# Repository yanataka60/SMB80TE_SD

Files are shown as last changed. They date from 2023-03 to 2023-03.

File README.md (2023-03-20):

# SHARP SM-B-80TEにSD-Cardとのロード、セーブ機能

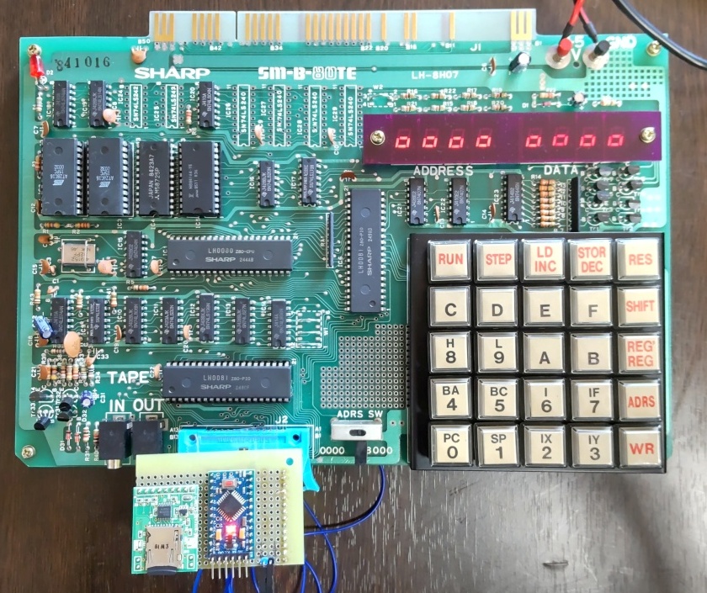
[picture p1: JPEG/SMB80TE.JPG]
TITLE


　シリアル同期通信によりSM-B-80TEとSD_ACCESS(ARDUINO+SD-CARD)とのロード、セーブを提供するルーチンです。

## 必要なもの
　Z80PIO 1個(標準搭載のZ80PIOとは別のZ80PIOが必要)

　SD_ACCESS基板(「SD_ACCESS」リポジトリ参照)

　2716 1個(MONITOR ROMを差し替えるなら2716 2個)

　ピンヘッダ、フラットケーブル、ブレッドボード・ジャンパーワイヤ等(SD_ACCESS基板の接続方法により適宜用意してください)

## 接続方法
SD_ACCESS(ARDUINO+SD-CARD)と拡張Z80PIOを接続します。拡張Z80PIO外部端子から接続する例を示します。

SD_ACCESS(ARDUINO+SD-CARD)については、「SD_ACCESS」リポジトリを参照してください。

|Arduino(SD_ACCESS)|拡張Z80PIO外部端子(SM-B-80TE)|
| --- | --- |
|5V|B8　5V|
|GND|B7　GND|
|9(FLG:output)|A4　PORTC BIT1(CHK:input)|
|8(OUT:output)|B4　PORTC BIT0(IN:input)|
|7(CHK:input)|A3　PORTC BIT3(FLG:output)|
|6(IN:input)|B3　PORTC BIT2(OUT:output)|

　今回はTK-85用に用意したSD_ACCESS(ARDUINO+SD-CARD)を流用して繋いでいます。

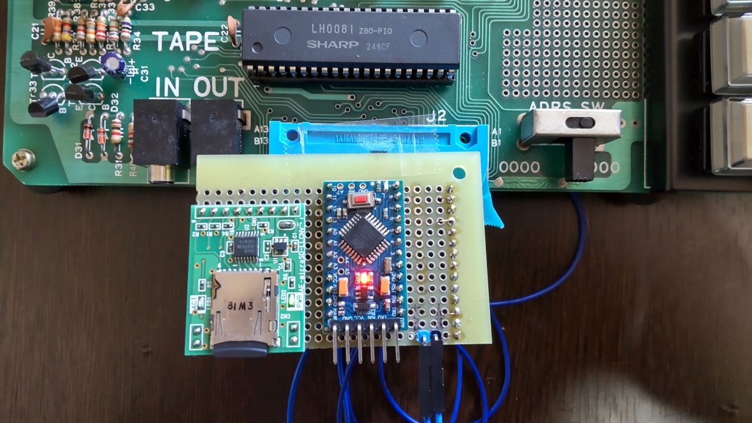
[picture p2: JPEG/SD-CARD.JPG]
SD-Cardアダプタ


### SM-B-80TE専用のSD_ACCESS基板を作ってみました。

　基板データは、Kicadフォルダにあります。

#### 部品
|番号|品名|数量|備考|
| --- | --- | --- | --- |
|J1|細ピンヘッダ又は基板用リードフレーム|1|秋月電子通商 PHA-1x40SG又はSHP-001|
||J2、J3のいずれか|||
|J2|Micro_SD_Card_Kit|1|秋月電子通商 AE-microSD-LLCNV|
|J3|MicroSD Card Adapter|1|Arduino等に使われる5V電源に対応したもの|
|U2|Arduino_Pro_Mini_5V|1||
||40PinICソケット|1||
|U1|Z80PIO|1|SM-B-80TEに増設済みであれば引き抜いて使用|

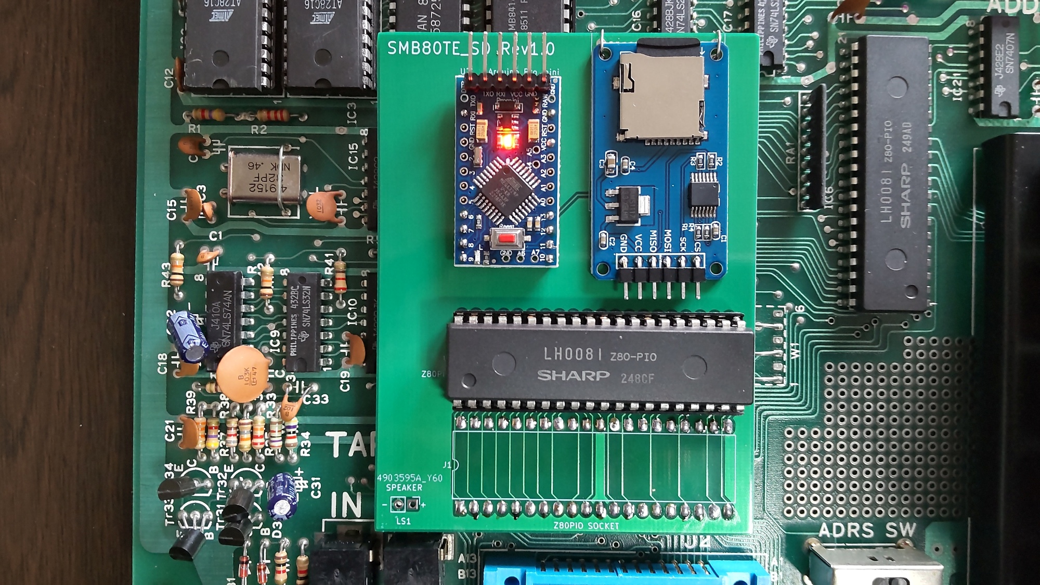
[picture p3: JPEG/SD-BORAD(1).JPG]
SD-BOARD1


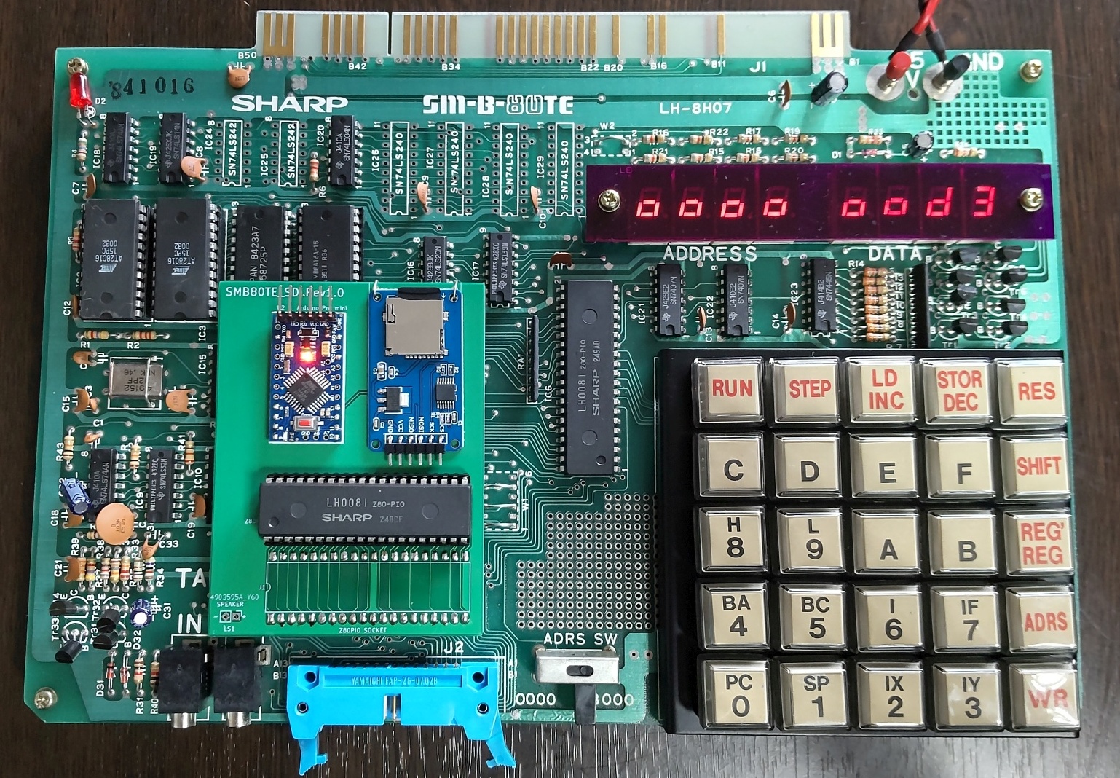
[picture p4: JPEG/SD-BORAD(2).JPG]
SD-BOARD2


## ROMへの書込み
　file_trans_SMB80TE.binを2716に書き込み、SM-B-80TEのIC3 ROMソケットに挿し込みます。

## MONITOR-ROMの差し替え
　SD用LOADルーチン(8800H)、SAVEルーチン(8803H)を直接実行することでSDへのLOAD、SAVEが行えますが、MONITOR-ROMにパッチを当て、SHIFT+A(SD-LOAD)、SHIFT+B(SD-SAVE)で使えるようにすると便利です。

　MONITOR-ROMの内容を読み出し、バイナリエディタ等で以下を修正し、2716に書き込み、MONITOR-ROMと差し替えます。

|ADDRESS(実ADDRESS)|変更前|変更後|
| --- | --- | --- |
|0060(8060)|FE|C3|
|0061(8061)|0C|06|
|0062(8062)|CA|88|

## SD-CARD
　FAT16又はFAT32が認識できます。

## 扱えるファイル
　拡張子btkとなっているバイナリファイルです。

　ファイル名は0000～FFFFまでの16進数4桁を付けてください。(例:1000.btk)

　この16進数4桁がSM-B-80TEからSD-Card内のファイルを識別するファイルNoとなります。

　btkの構造は、バイナリファイル本体データの先頭に開始アドレス、終了アドレスの4Byteのを付加した形になっています。(SAMPLEフォルダの0001.bin、0001.btkを参照)

　パソコンのクロスアセンブラ等でSM-B-80TE用の実行binファイルを作成したらバイナリエディタ等で先頭に開始アドレス、終了アドレスの4Byteを付加し、ファイル名を変更したものをSD-Cardのルートディレクトリに保存すればSM-B-80TEから呼び出せるようになります。

## 操作方法
　異常が無いと思われるのにエラーとなってしまう場合にはSD-CardアダプタのArduinoとSM-B-80TEの両方をリセットしてからやり直してみてください。

### Load
 (直接実行する場合)8800H

 (MONITOR-ROMを差し替えた場合)SHIFT+A

　ADDRESS LEDに「L-F」と表示されるのでファイルNo(xxxx)を16進数4桁で入力してWRキーを押します。

　　　xxxx.BTKをBTKヘッダ情報で示されたアドレスにロードします。ただし、07B0H～07FFHまでの範囲はライトプロテクトされます。

　正常にLoadが完了するとアドレス部にスタートアドレス、データ部にエンドアドレスが表示されます。スタートアドレスが実行開始アドレスであればそのままRUNキーを押すことでプログラムが実行できます。

　「F0F0F0F0F0」と表示された場合はSD-Card未挿入、「F1F1F1F1F1」と表示された場合はファイルNoのファイルが存在しない場合です。確認してください。

### Save
 (直接実行する場合)8803H

 (MONITOR-ROMを差し替えた場合)SHIFT+B

　ADDRESS LEDに「S-F」と表示されるのでファイルNo(xxxx)を16進数4桁で入力してWRキーを押します。

　ADDRESS LEDに「S-S」と表示されるのでSAVEしたい範囲のSTART ADDRESSを16進数4桁で入力してWRキーを押します。

　ADDRESS LEDに「S-E」と表示されるのでSAVEしたい範囲のEND ADDRESSを16進数4桁で入力してWRキーを押します。

　正常にSaveが完了するとアドレス部にスタートアドレス、データ部にエンドアドレスが表示されます。

　「FFFFFFFF」と表示された場合はSD-Card未挿入です。確認してください。

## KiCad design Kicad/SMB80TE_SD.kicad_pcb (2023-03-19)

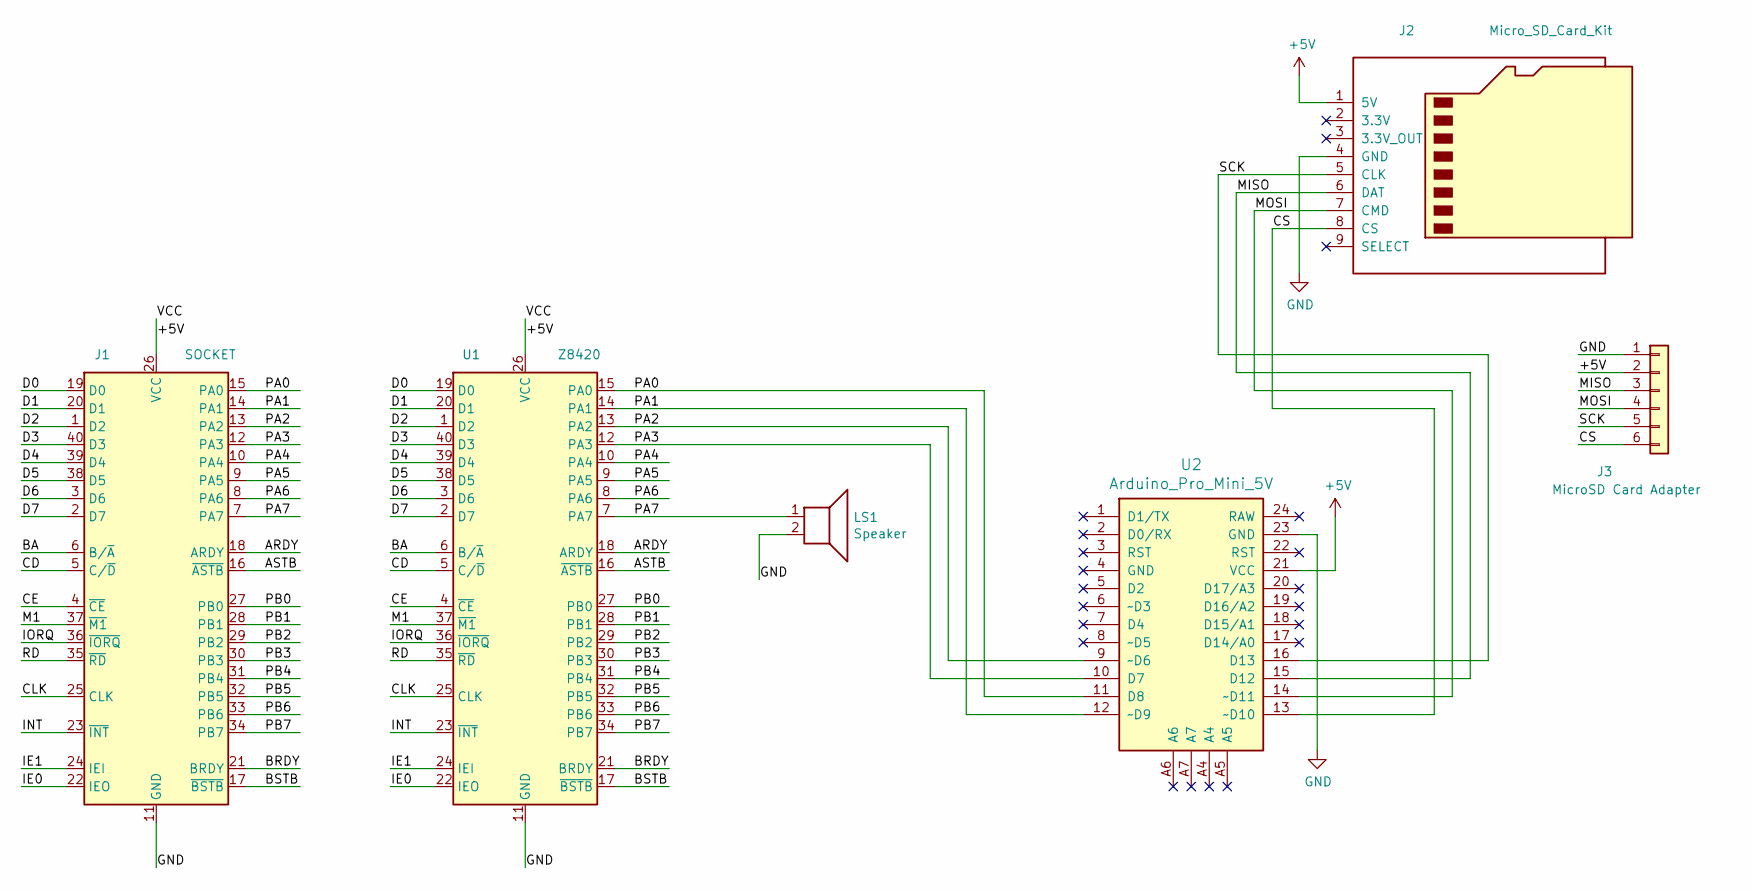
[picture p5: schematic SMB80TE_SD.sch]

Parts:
J1: SOCKET; DIP-40_W15.24mm_LongPads
J2: Micro_SD_Card_Kit; AE-microSD-LLCNV
J3: MicroSD Card Adapter; PinSocket_1x06_P2.54mm_Vertical
LS1: Speaker; PinHeader_1x02_P2.54mm_Vertical
U1: Z8420; DIP-40_W15.24mm_LongPads
U2: Arduino_Pro_Mini_5V; Arduino_Pro_Mini

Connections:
+5V: J1.26 (VCC), J2.1 (5V), J3.2, U1.26 (VCC), U2.21 (VCC)
/ARDY: J1.18 (ARDY), U1.18 (ARDY)
/ASTB: J1.16 (~ASTB~), U1.16 (~ASTB~)
/BA: J1.6 (B/~A~), U1.6 (B/~A~)
/BRDY: J1.21 (BRDY), U1.21 (BRDY)
/BSTB: J1.17 (~BSTB~), U1.17 (~BSTB~)
/CD: J1.5 (C/~D~), U1.5 (C/~D~)
/CE: J1.4 (~CE~), U1.4 (~CE~)
/CLK: J1.25 (CLK), U1.25 (CLK)
/CS: J2.8 (CS), J3.6, U2.13 (~~D10)
/D0: J1.19 (D0), U1.19 (D0)
/D1: J1.20 (D1), U1.20 (D1)
/D2: J1.1 (D2), U1.1 (D2)
/D3: J1.40 (D3), U1.40 (D3)
/D4: J1.39 (D4), U1.39 (D4)
/D5: J1.38 (D5), U1.38 (D5)
/D6: J1.3 (D6), U1.3 (D6)
/D7: J1.2 (D7), U1.2 (D7)
/IE0: J1.22 (IEO), U1.22 (IEO)
/IE1: J1.24 (IEI), U1.24 (IEI)
/INT: J1.23 (~INT~), U1.23 (~INT~)
/IORQ: J1.36 (~IORQ~), U1.36 (~IORQ~)
/M1: J1.37 (~M1~), U1.37 (~M1~)
/MISO: J2.6 (DAT), J3.3, U2.15 (D12)
/MOSI: J2.7 (CMD), J3.4, U2.14 (~~D11)
/PA0: J1.15 (PA0), U1.15 (PA0), U2.11 (D8)
/PA1: J1.14 (PA1), U1.14 (PA1), U2.12 (~~D9)
/PA2: J1.13 (PA2), U1.13 (PA2), U2.9 (~~D6)
/PA3: J1.12 (PA3), U1.12 (PA3), U2.10 (D7)
/PA4: J1.10 (PA4), U1.10 (PA4)
/PA5: J1.9 (PA5), U1.9 (PA5)
/PA6: J1.8 (PA6), U1.8 (PA6)
/PA7: J1.7 (PA7), LS1.1, U1.7 (PA7)
/PB0: J1.27 (PB0), U1.27 (PB0)
/PB1: J1.28 (PB1), U1.28 (PB1)
/PB2: J1.29 (PB2), U1.29 (PB2)
/PB3: J1.30 (PB3), U1.30 (PB3)
/PB4: J1.31 (PB4), U1.31 (PB4)
/PB5: J1.32 (PB5), U1.32 (PB5)
/PB6: J1.33 (PB6), U1.33 (PB6)
/PB7: J1.34 (PB7), U1.34 (PB7)
/RD: J1.35 (~RD~), U1.35 (~RD~)
/SCK: J2.5 (CLK), J3.5, U2.16 (D13)
GND: J1.11 (GND), J2.4 (GND), J3.1, LS1.2, U1.11 (GND), U2.23 (GND)

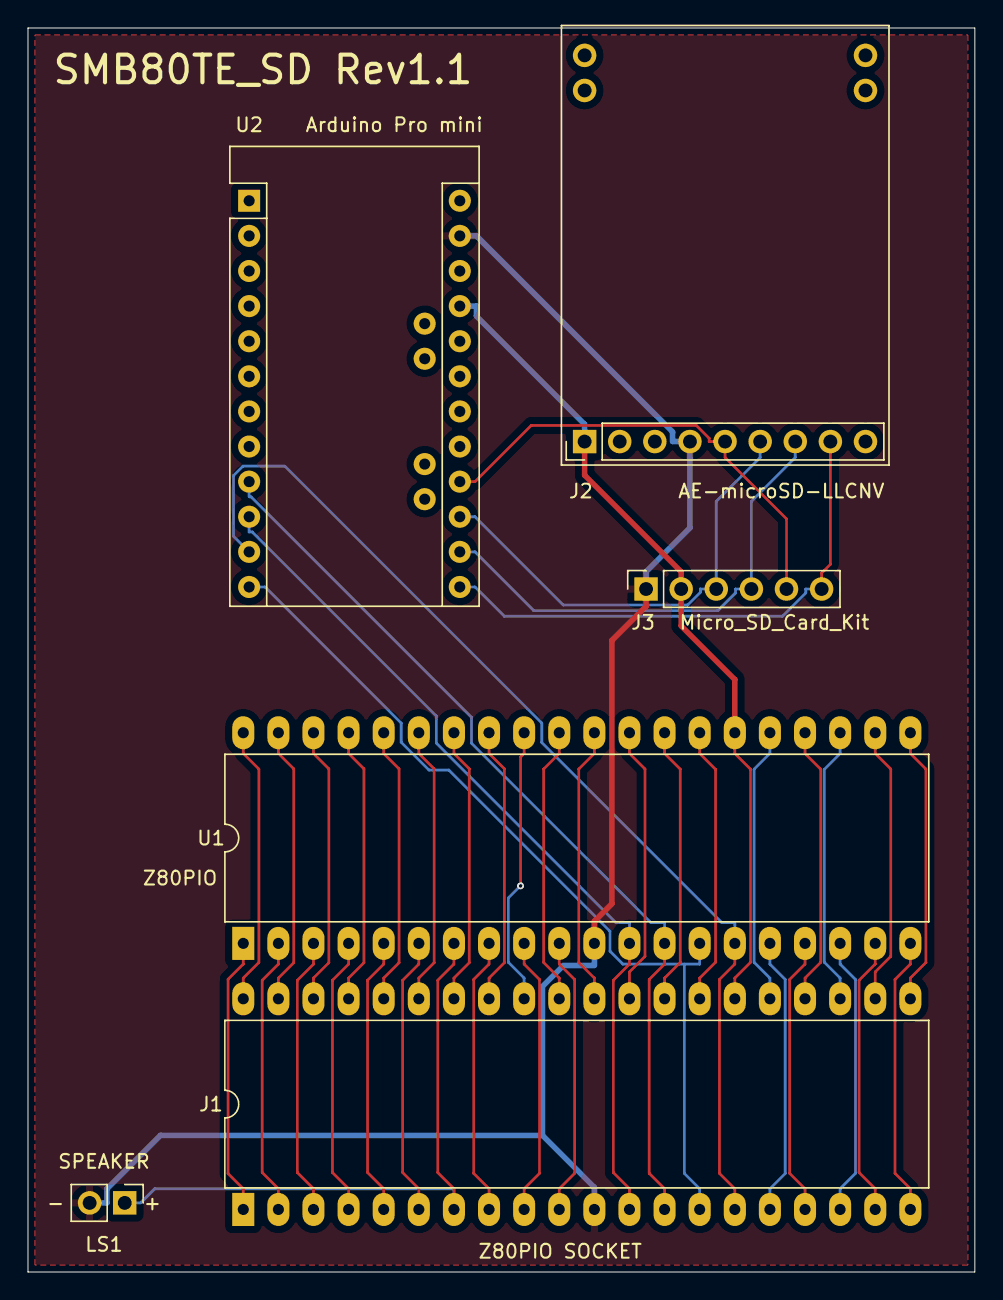
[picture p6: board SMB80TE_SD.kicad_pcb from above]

Board: 2 copper layers, 68.5 x 90.0 mm, 6 parts (0 on the bottom side), 44 nets.
